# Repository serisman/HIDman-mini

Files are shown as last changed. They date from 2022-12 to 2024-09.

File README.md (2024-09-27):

# HIDman-mini
A USB keyboard/mouse to PS/2 (or AT, Serial) computer adapter.

Based on and compatible with: [HIDman](https://github.com/rasteri/HIDman) by [rasteri](https://github.com/rasteri)
 - In the Makefile, make sure the correct `BOARD_TYPE` is selected and then make sure `OSC_TYPE = OSC_INTERNAL` is enabled and `OSC_TYPE = OSC_EXTERNAL` is disabled.  Re-compile and flash the firmware following the instructions found in the HIDman firmware.
   - For HIDman-mini: Choose `BOARD_TYPE = BOARD_AXP` (for ps/2 and serial support), or `BOARD_TYPE = BOARD_MINI` (for just ps/2 support).
   - For HIDman-micro: Choose `BOARD_TYPE = BOARD_MICRO` (only has ps/2 support).
     - Optionally switch to `BOARD_OPTIONS = OPT_SWAP_KBD_MSC` to make it a bit easier to wire up a combo ps/2 port.

### PCBs
- [HIDman-mini](KiCad%20PCBs/HIDman-mini/)
- [HIDman-micro](KiCad%20PCBs/HIDman-micro/)
- [DB9-to-TTL](KiCad%20PCBs/DB9-to-TTL/)

### 3D Printer Models
- [Cover for HIDman-mini](3D%20Printer%20Models/HIDman-mini/)
- [Shell for DB9-to-TTL](3D%20Printer%20Models/DB9-Shell/)

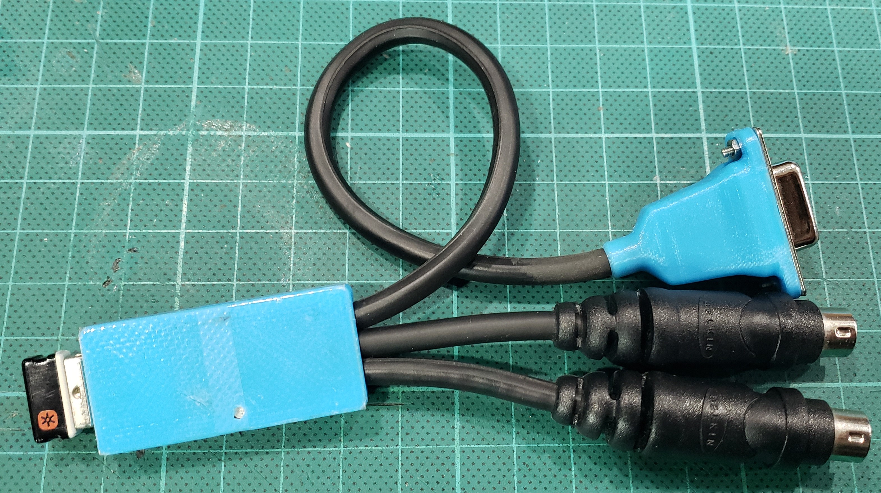
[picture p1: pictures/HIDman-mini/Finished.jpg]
Finished


### Schematics
(for HIDman-mini)
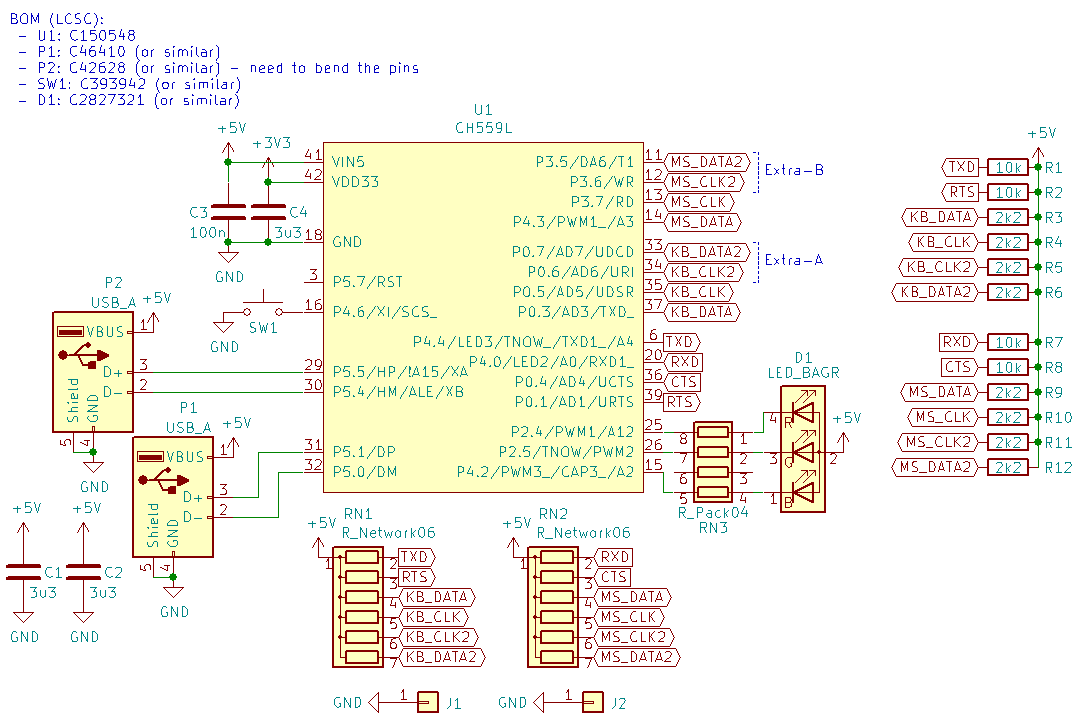
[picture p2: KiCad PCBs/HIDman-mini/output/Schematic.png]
Schematic


(for DB9-to-TTL)
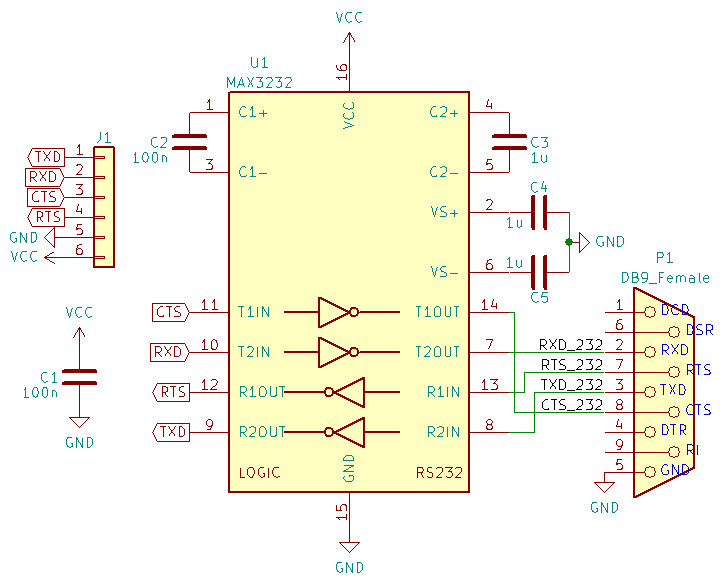
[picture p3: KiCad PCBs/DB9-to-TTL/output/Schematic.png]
Schematic


NOTE: Remember to cross-over TxD <--> RxD, and RTS <--> CTS when connecting the two PCBs!

### Optional Configuration: Combo PS/2 Keyboard/Mouse Connector
(for computers that support it)
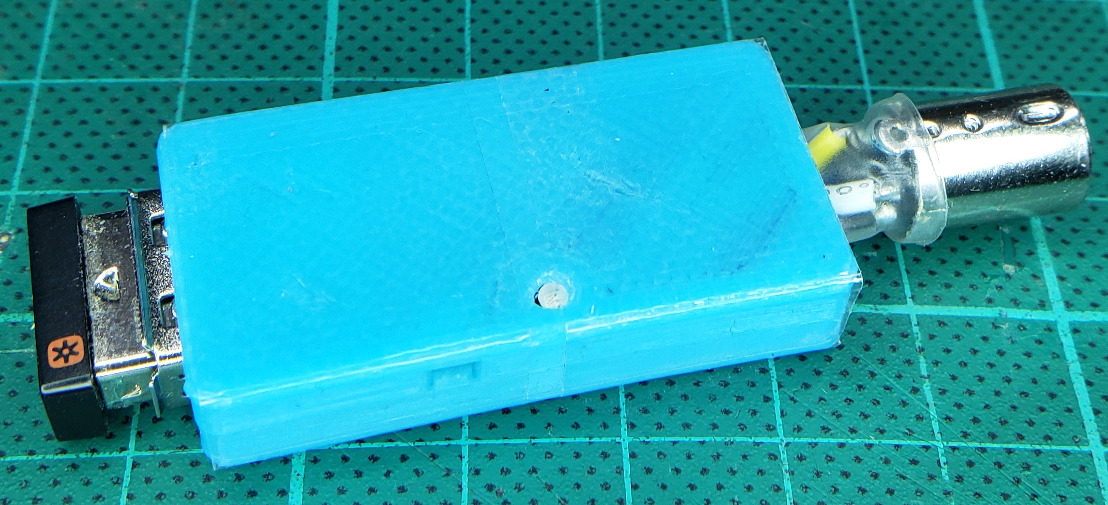
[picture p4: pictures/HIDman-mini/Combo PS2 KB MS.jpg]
Combo PS/2 Keyboard/Mouse

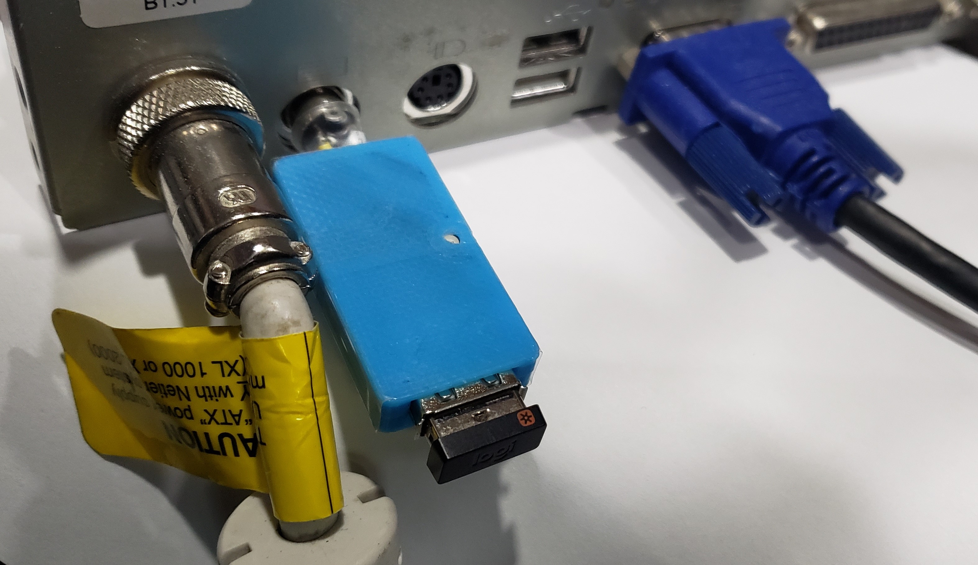
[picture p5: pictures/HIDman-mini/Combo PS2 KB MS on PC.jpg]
Combo PS/2 Keyboard/Mouse on PC


### Copyright and License:
- Copyright (C) 2022 - serisman (github@serisman.com)
- License: [GPL v3 (or later)](LICENSE)

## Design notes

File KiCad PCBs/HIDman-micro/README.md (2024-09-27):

[Home](/README.md)
# PCB: HIDman-micro

Order from [OSHPARK](https://oshpark.com/shared_projects/RKMXx0oz) or upload [gerber.zip](output/gerber.zip) to your favorite PCB board fabricator.

### Notes:
- **WARNING!** Make sure you install the USB port in the correct orientation!
- **WARNING!** Double and Triple check your PS/2 cable pinout to make sure you don't feed 5V where it shouldn't go!

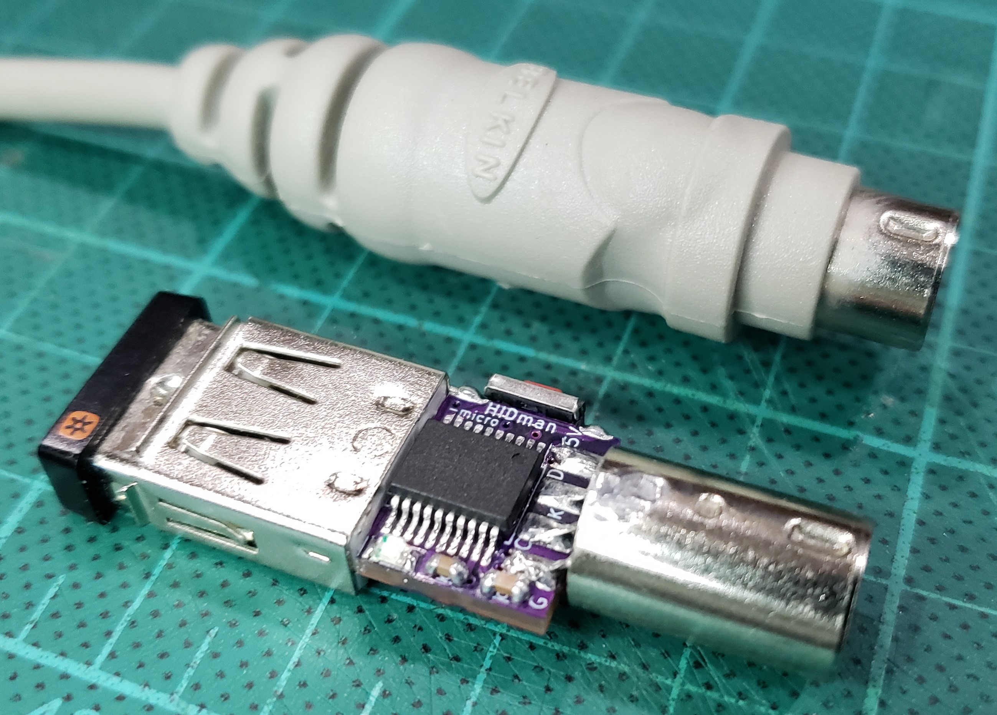
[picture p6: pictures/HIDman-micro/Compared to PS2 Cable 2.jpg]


### Firmware

Compatible with HIDman firmware: https://github.com/rasteri/HIDman

```
make clean
make BOARD_TYPE=HIDMAN_MICRO OSC_TYPE=OSC_INTERNAL flash
... or (if you want to swap Keyboard-Data with Mouse-Clock for easier soldering of combo PS/2 port) ...
make clean
make BOARD_TYPE=HIDMAN_MICRO BOARD_OPTIONS=OPT_SWAP_KBD_MSC OSC_TYPE=OSC_INTERNAL flash
```

### Schematic
- USB port P1 (on bottom side) is required for loading code, and can be used for USB keyboard/mouse (including keyboard/mouse combo wireless adapters).
- Hold down SW1 while plugging USB port into computer to force bootloader.
- Resistors are 0603
- Capacitors are 0603 (100n and 3u3) and 0805 (10u)

**WARNING!** This uses a different pinout than HIDman-mini.  Runtime detection can read P4.7, check if it is LOW or floating, and adjust the PS/2 pins accordingly.

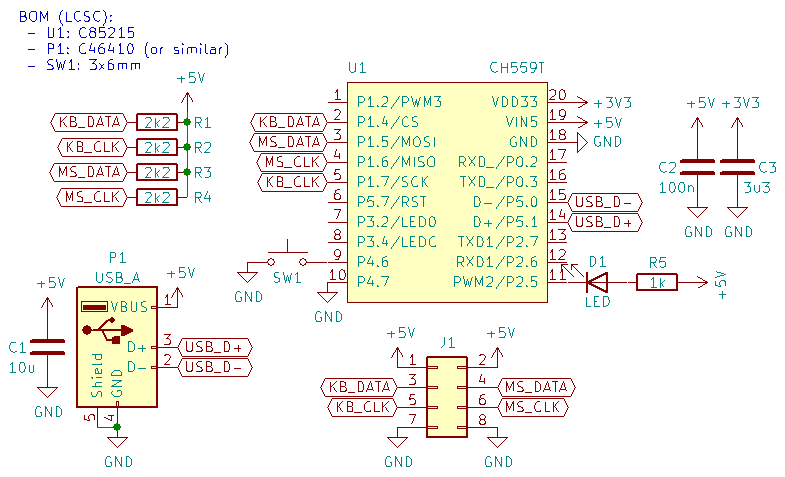
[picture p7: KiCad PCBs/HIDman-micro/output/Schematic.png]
Schematic


### Soldered PCB
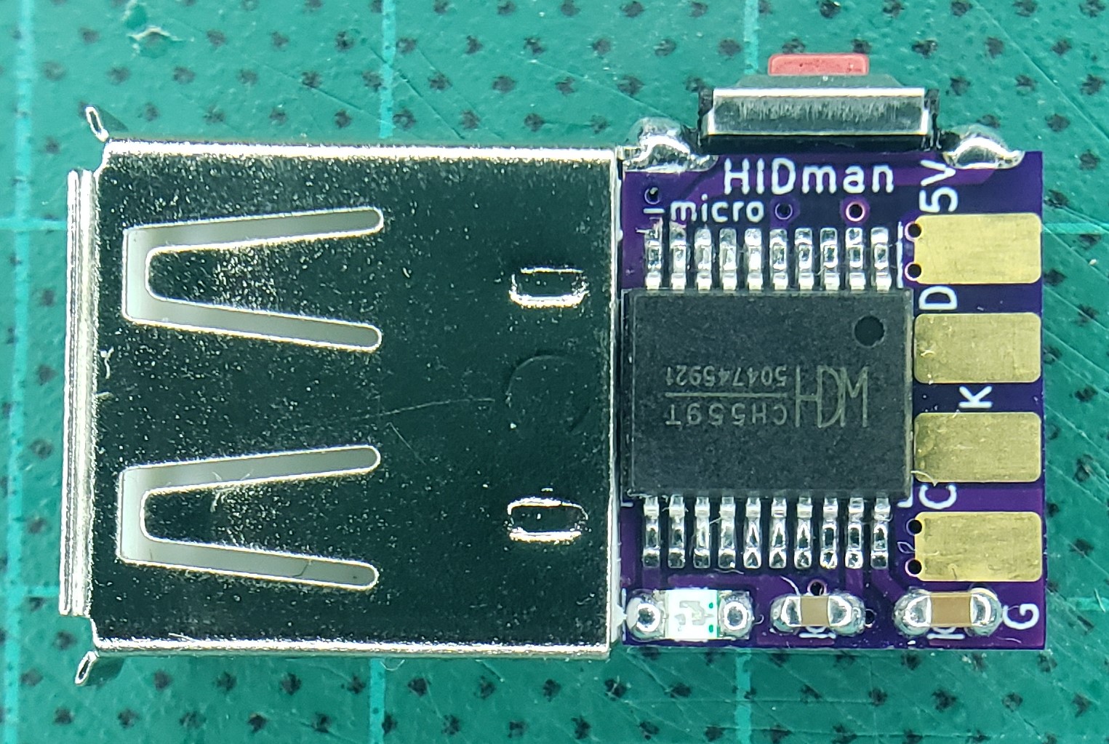
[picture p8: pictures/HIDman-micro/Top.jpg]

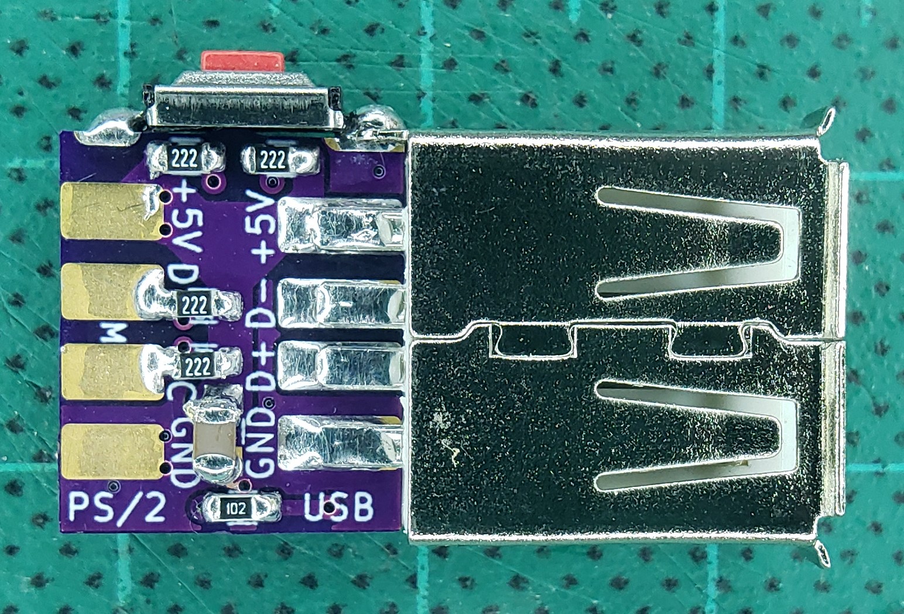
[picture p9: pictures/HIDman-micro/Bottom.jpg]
Bottom


### 3D Render
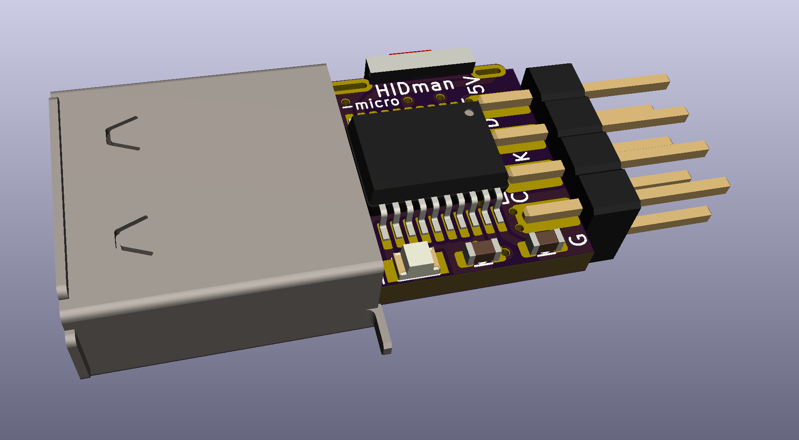
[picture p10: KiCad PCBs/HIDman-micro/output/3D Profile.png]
Profile

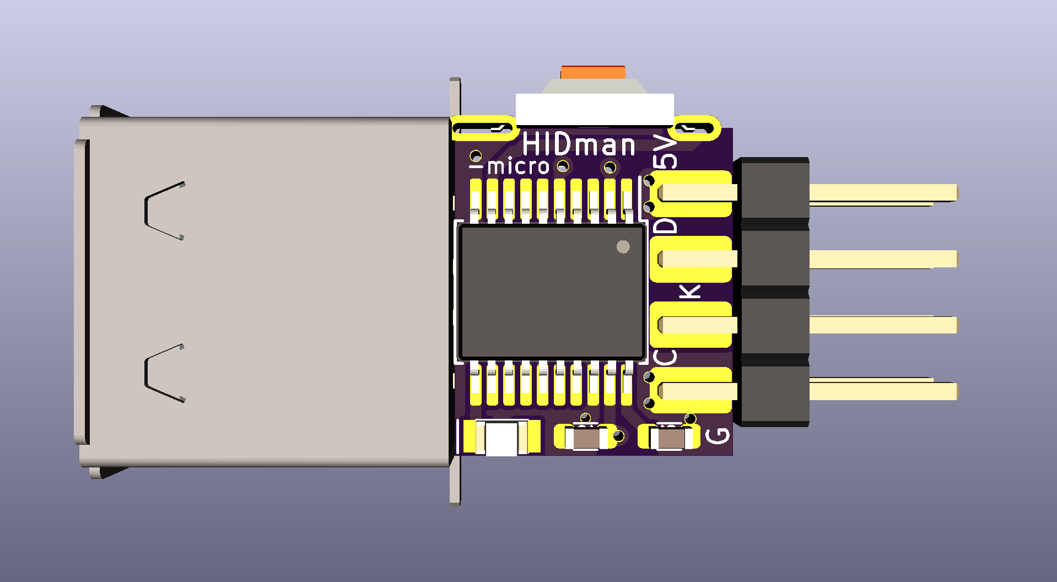
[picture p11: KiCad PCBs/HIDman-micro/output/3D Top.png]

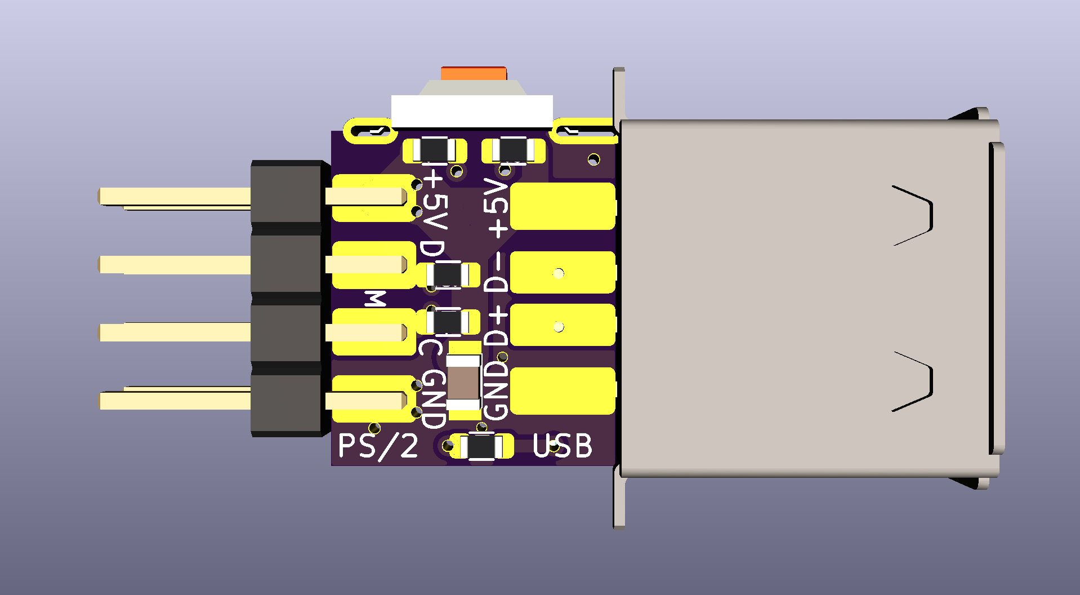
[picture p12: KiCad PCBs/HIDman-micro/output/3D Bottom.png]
Bottom


### Raw PCB
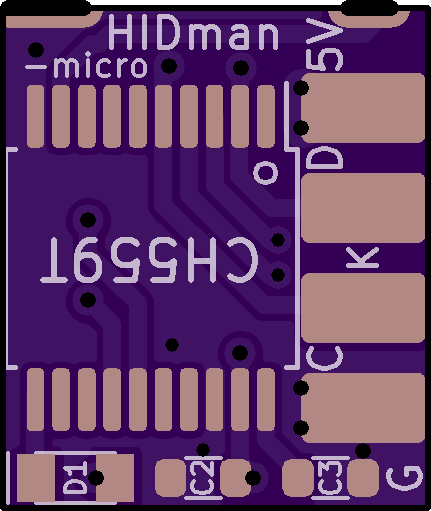
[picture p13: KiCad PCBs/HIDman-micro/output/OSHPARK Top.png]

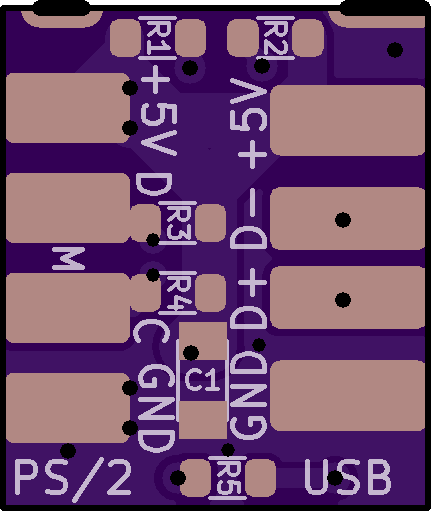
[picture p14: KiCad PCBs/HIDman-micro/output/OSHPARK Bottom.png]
Bottom


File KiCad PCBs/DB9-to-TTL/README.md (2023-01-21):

[Home](/README.md)
# PCB: DB9-to-TTL

Order from [OSHPARK](https://oshpark.com/shared_projects/djSCnWyn) or upload [gerber.zip](output/gerber.zip) to your favorite PCB board fabricator.

### Notes:
- Remember to cross-over TxD <--> RxD, and RTS <--> CTS when connecting to the main PCB!
- The older MAX232 can be used in place of the MAX3232.  Might need to change the capacitor values.

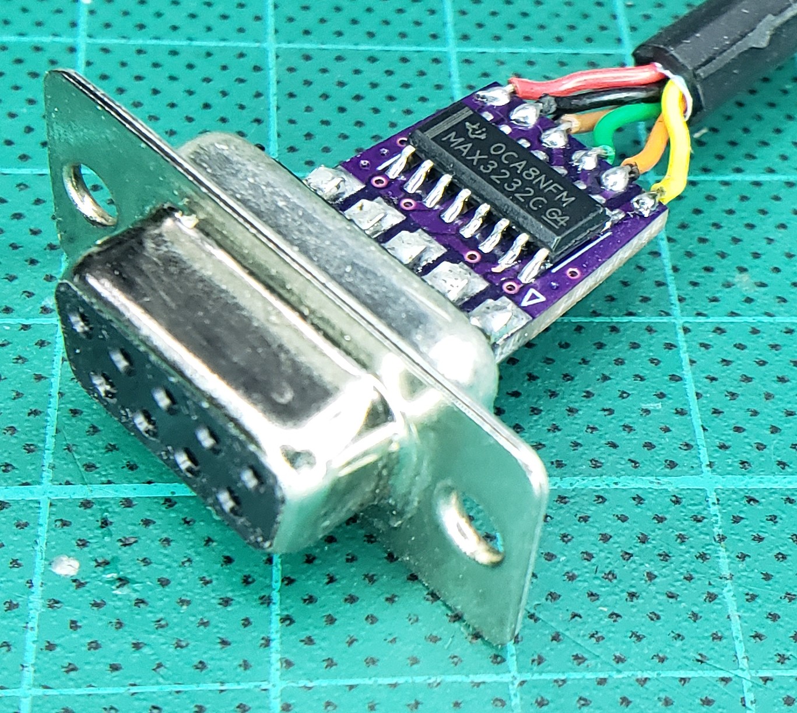
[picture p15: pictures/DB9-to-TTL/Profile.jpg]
Profile


### Schematic
- Capacitors are 0603

Schematic

### Soldered PCB
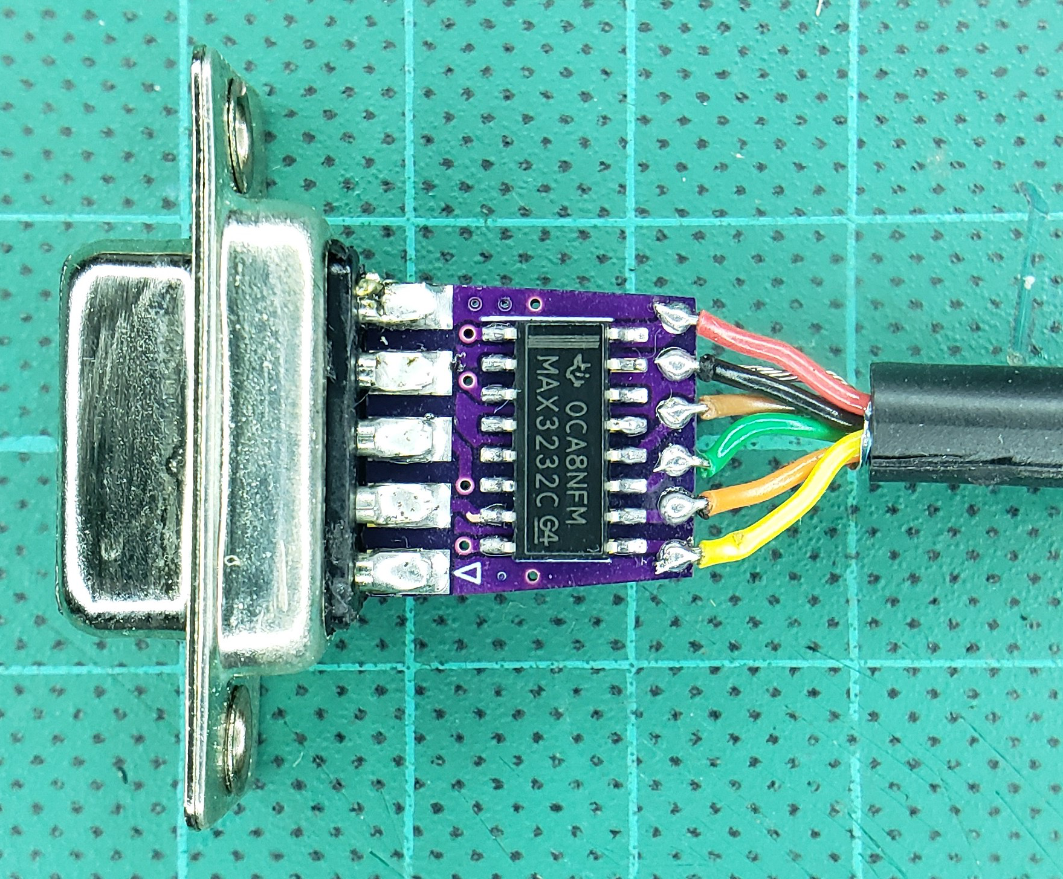
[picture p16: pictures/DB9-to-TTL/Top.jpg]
Top

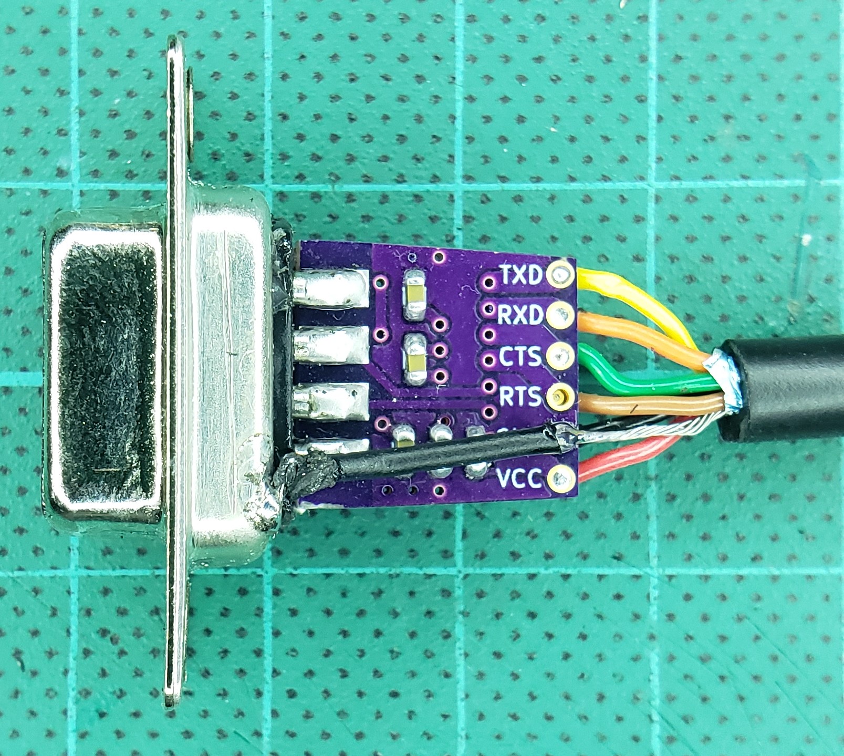
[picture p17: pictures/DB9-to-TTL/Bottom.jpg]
Bottom


### Raw PCB
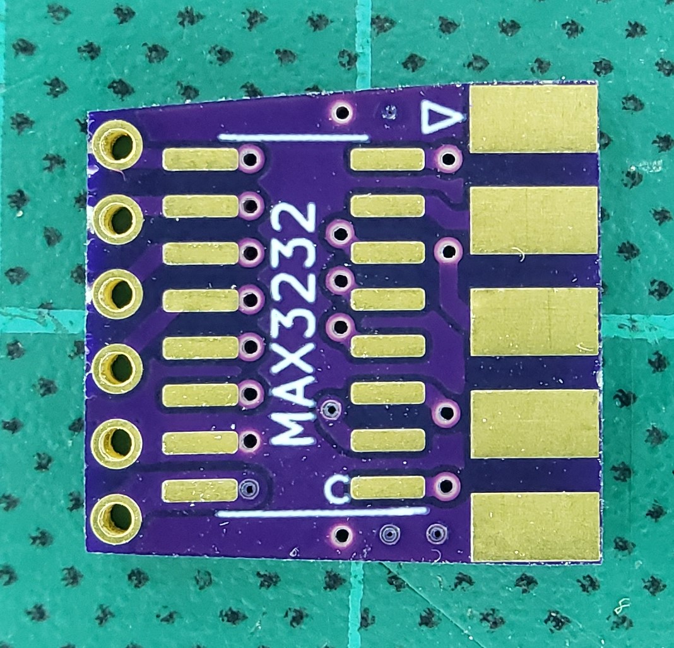
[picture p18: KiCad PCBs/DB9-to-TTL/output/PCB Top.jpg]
PCB Top

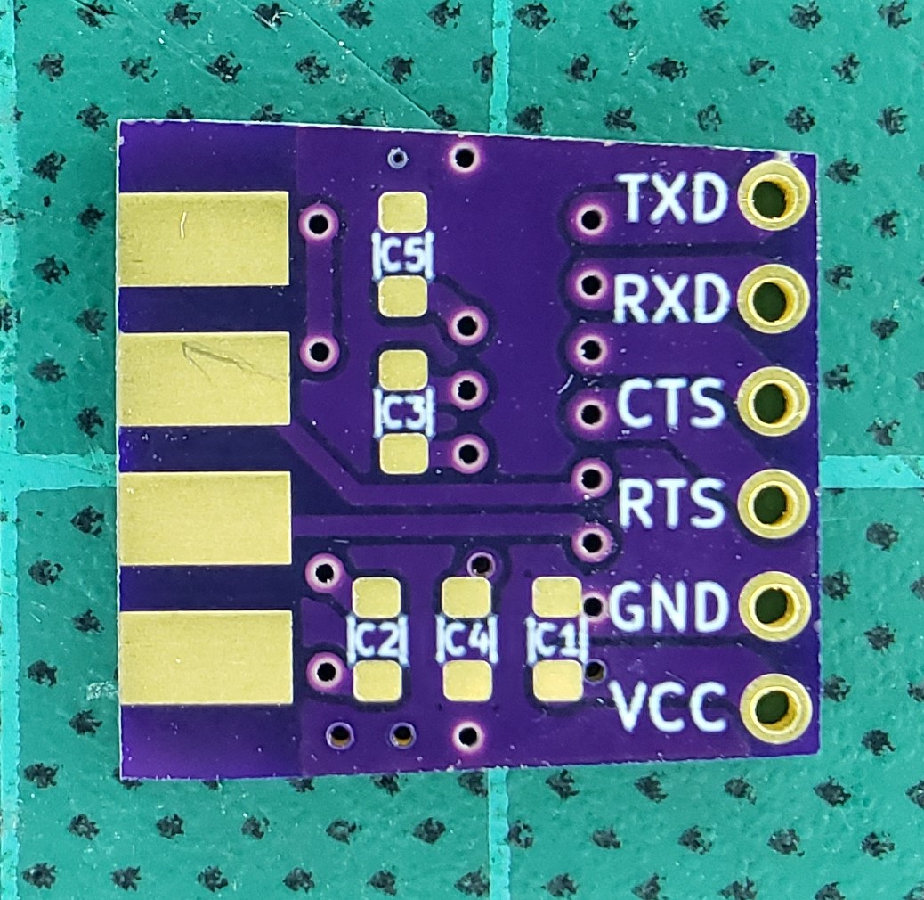
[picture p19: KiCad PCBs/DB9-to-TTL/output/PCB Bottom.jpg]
PCB Bottom


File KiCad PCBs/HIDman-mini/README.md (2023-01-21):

[Home](/README.md)
# PCB: HIDman-mini

Order from [OSHPARK](https://oshpark.com/shared_projects/GPxhWAbz) or upload [gerber.zip](output/gerber.zip) to your favorite PCB board fabricator.

### Notes:
- **WARNING!** Make sure you install the CH559 IC in the correct orientation!  There are three dots, making it confusing at a glance (as me how I know!)
- **WARNING!** Make sure you install the USB port(s) in the correct orientation!
- **WARNING!** Double and Triple check your PS/2 cable pinout to make sure you don't feed 5V where it shouldn't go!

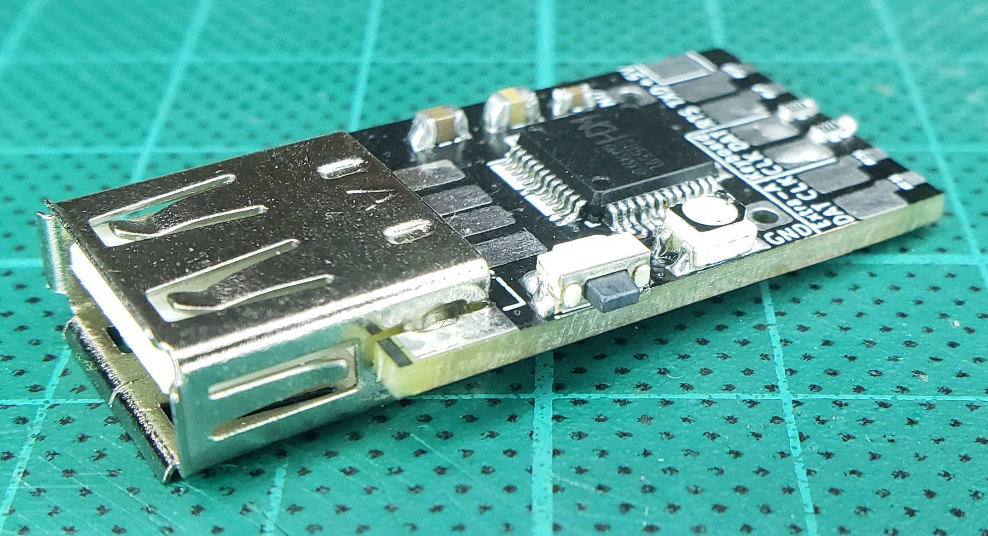
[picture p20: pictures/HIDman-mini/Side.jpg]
Profile


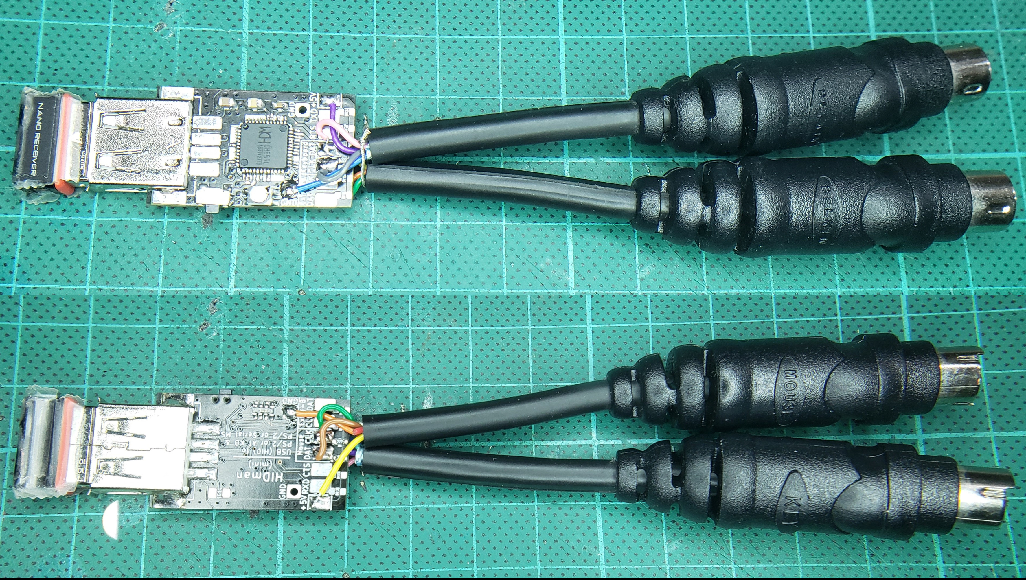
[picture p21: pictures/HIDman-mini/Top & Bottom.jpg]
Soldered


### Schematic
- USB port P1 (on bottom side) is required for loading code, and can be used for USB keyboard/mouse (including keyboard/mouse combo wireless adapters).  It can be installed in the middle of the PCB if USB port P2 is not installed.
- USB port P2 (on top side) is optional, but can be installed if a 2nd USB port is needed.  If installed, USB port P1 will have to be lowered a bit.
- Hold down SW1 while plugging USB port P1 into computer to force bootloader.
- Extra-A and Extra-B are not used for anything (yet).  Therefore R5,R6,R11,R12 are not needed.
- R1,R2,R7,R8 are probably not needed.
- Resistors are 0603
- Capacitors are 0603 (100n) and 0805 (3u3+)
- RN1/RN2 are not actually resistor networks.  They are providing the top/bottom solder pads.
- RN3 is 1k (or whatever works with choosen RGB LED)

Schematic

### Soldered PCB
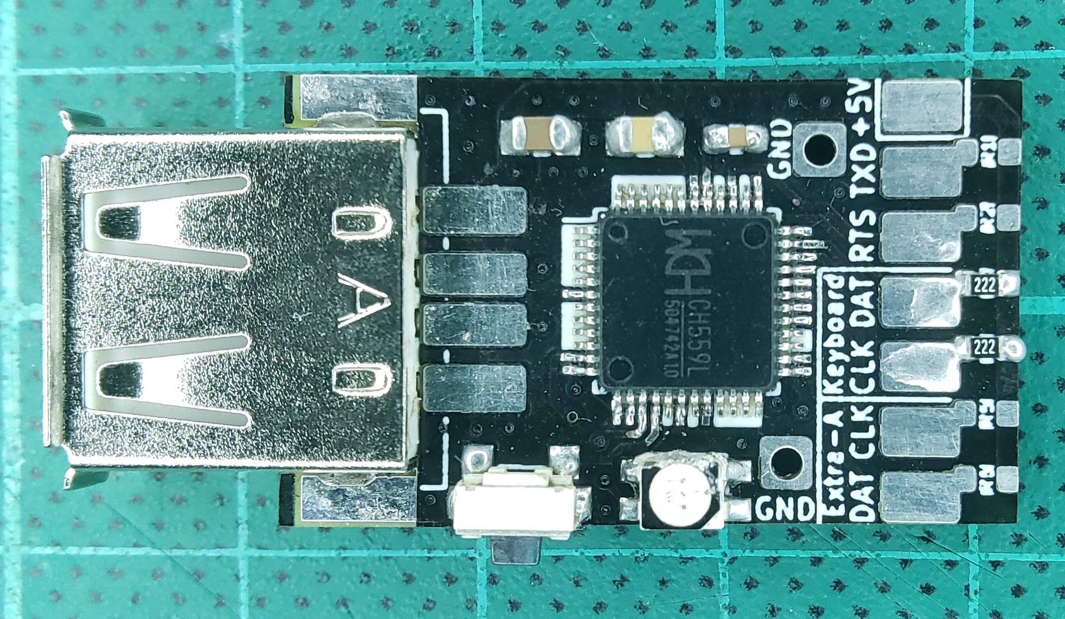
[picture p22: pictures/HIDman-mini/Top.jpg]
Top

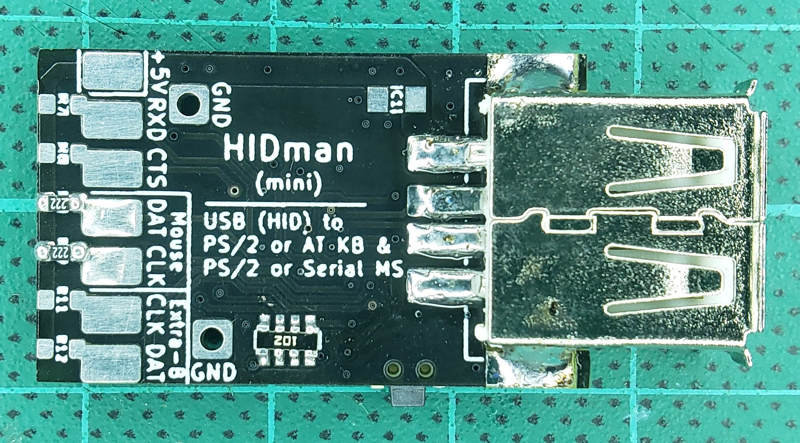
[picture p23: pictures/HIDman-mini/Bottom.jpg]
Bottom


### Raw PCB
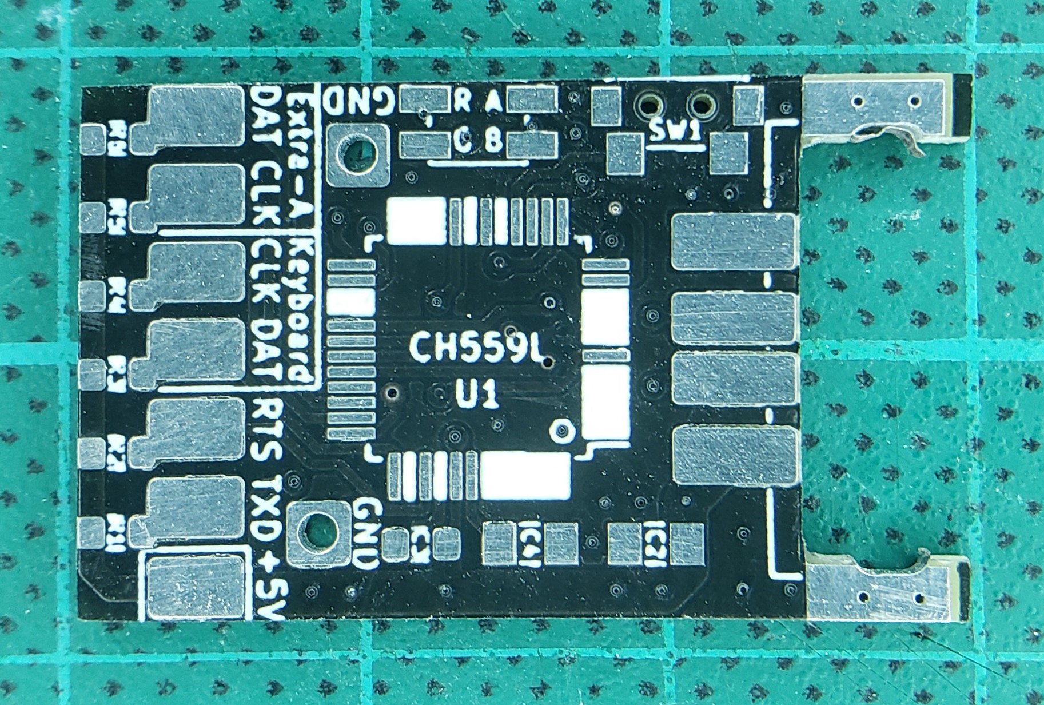
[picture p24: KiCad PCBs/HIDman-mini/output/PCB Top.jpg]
PCB Top

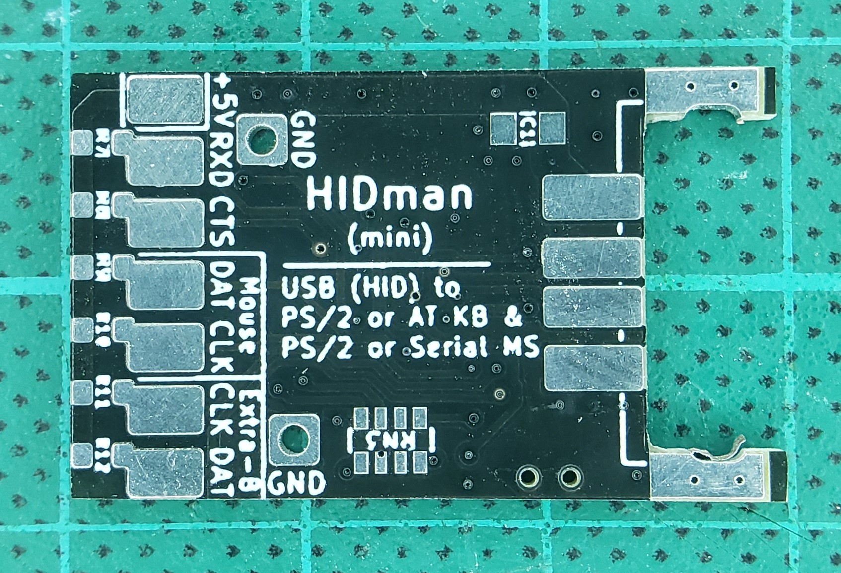
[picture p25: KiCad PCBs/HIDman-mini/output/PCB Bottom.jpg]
PCB Bottom


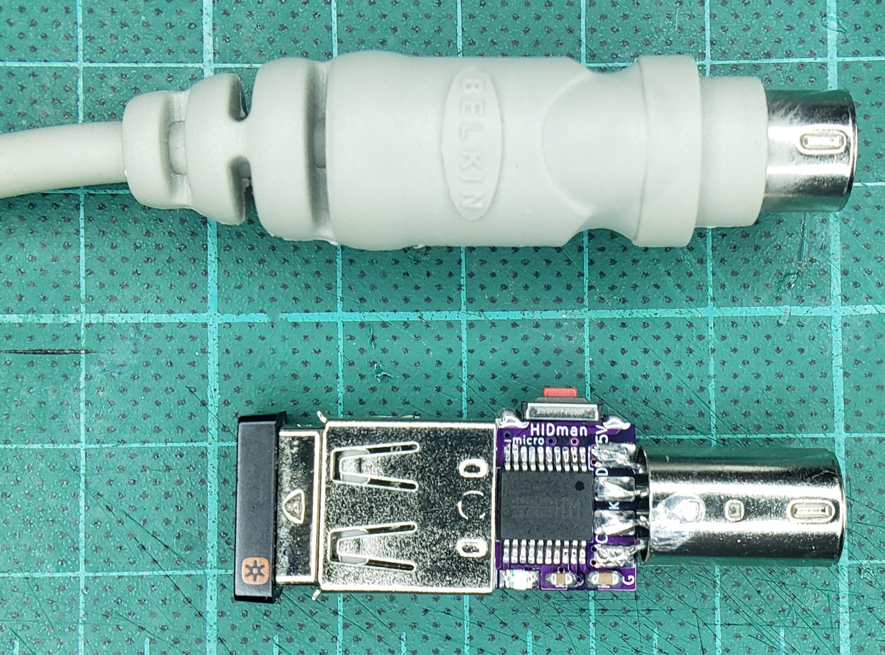
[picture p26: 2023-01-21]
pictures/HIDman-micro/Compared to PS2 Cable.jpg

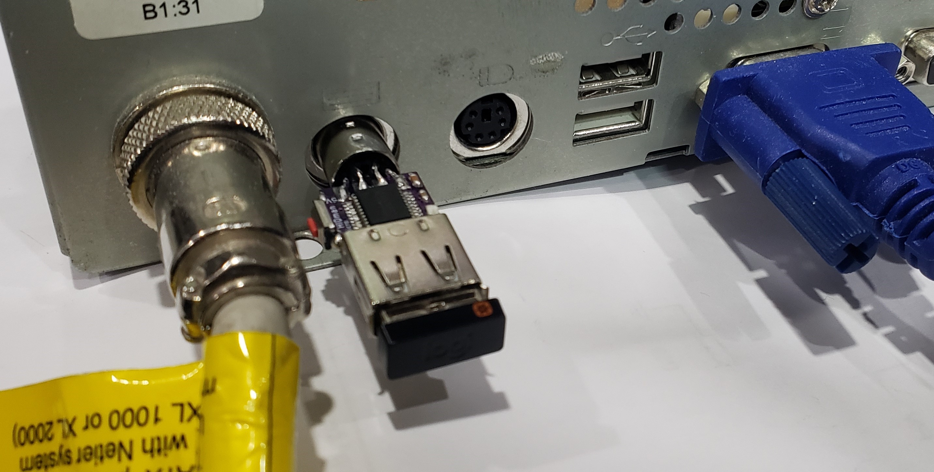
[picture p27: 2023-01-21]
pictures/HIDman-micro/Combo PS2 KB MS on PC.jpg

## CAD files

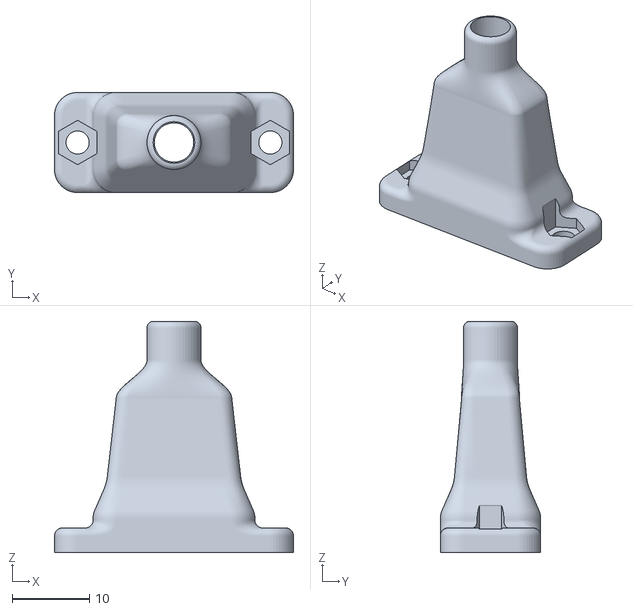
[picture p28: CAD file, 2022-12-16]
3D Printer Models/DB9-Shell/DB9-Shell.stl
31.0 x 13.0 x 30.0

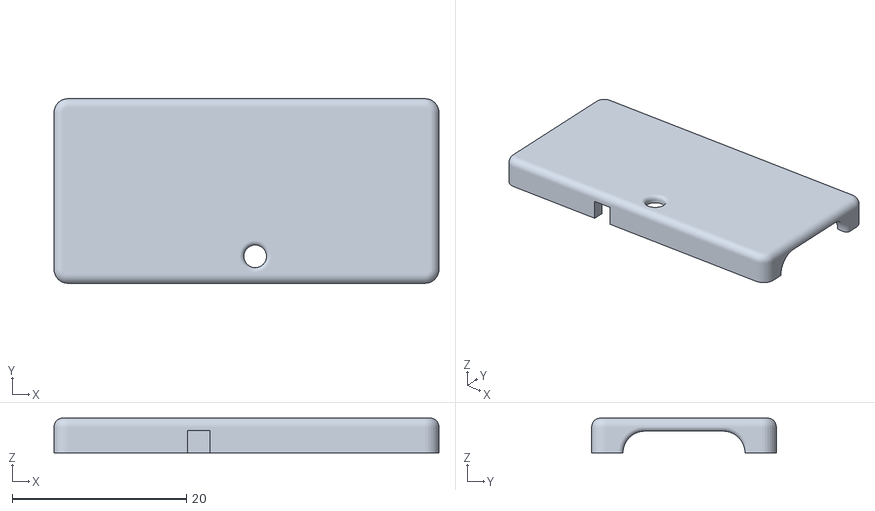
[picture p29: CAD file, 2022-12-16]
3D Printer Models/HIDman-mini/HIDman-mini_Top.stl
44.2 x 21.2 x 4.00

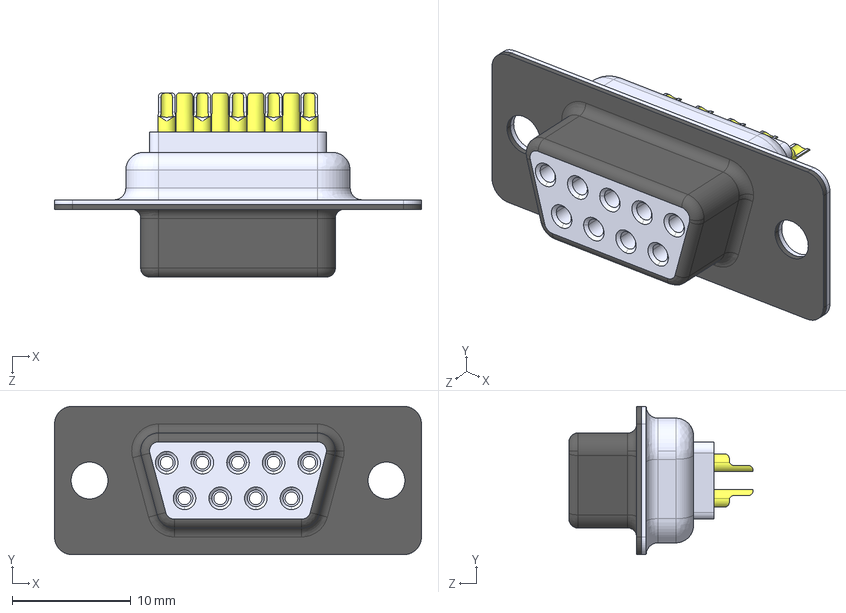
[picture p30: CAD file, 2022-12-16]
KiCad PCBs/DB9-to-TTL/_3dshapes/DB9_Female.step
30.9 x 12.5 x 15.5 mm
H_F_Fr_1
I_F_Fr_1 x 2
H_F_Ba_1
Connector_1 x 9

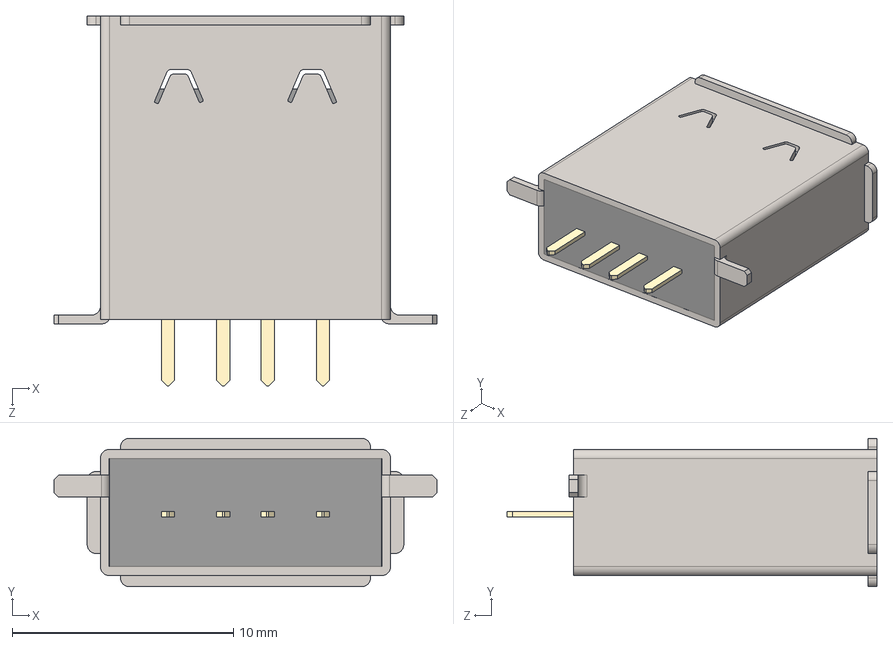
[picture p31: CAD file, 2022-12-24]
KiCad PCBs/HIDman-micro/_3dshapes/USB-A-Edge.step
17.3 x 6.70 x 16.7 mm

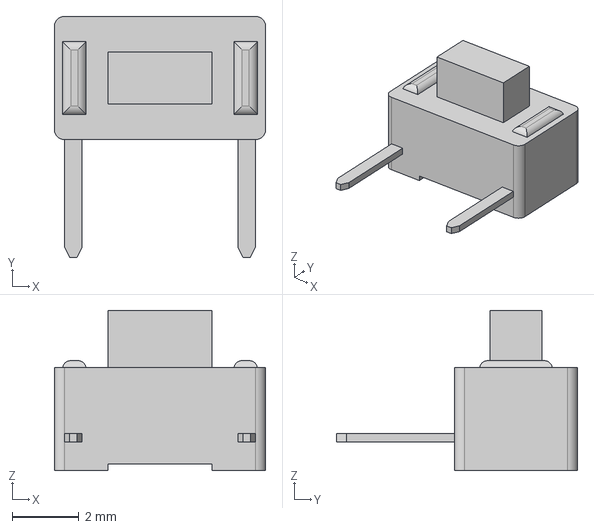
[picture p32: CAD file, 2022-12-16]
KiCad PCBs/HIDman-mini/_3dshapes/Pushbutton_Side.step
6.34 x 7.23 x 4.80 mm

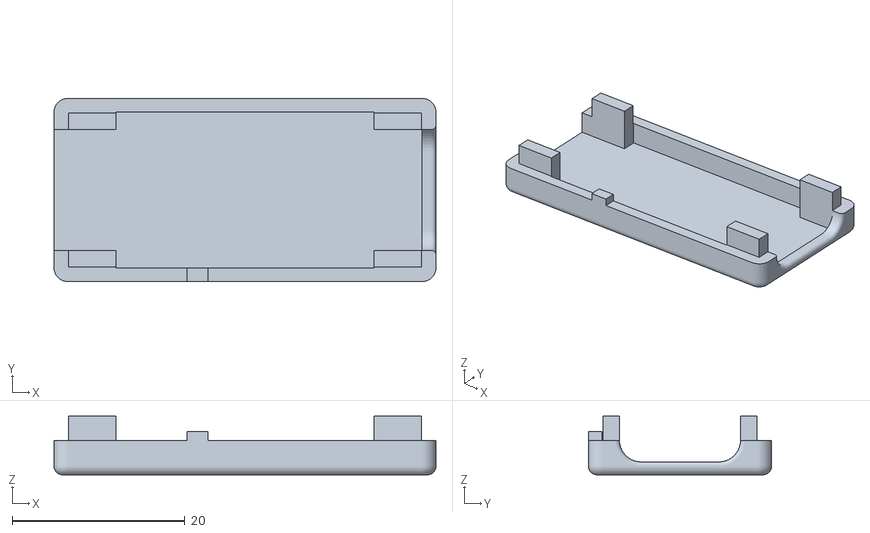
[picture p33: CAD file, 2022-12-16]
3D Printer Models/HIDman-mini/HIDman-mini_Base.stl
44.2 x 21.2 x 6.80

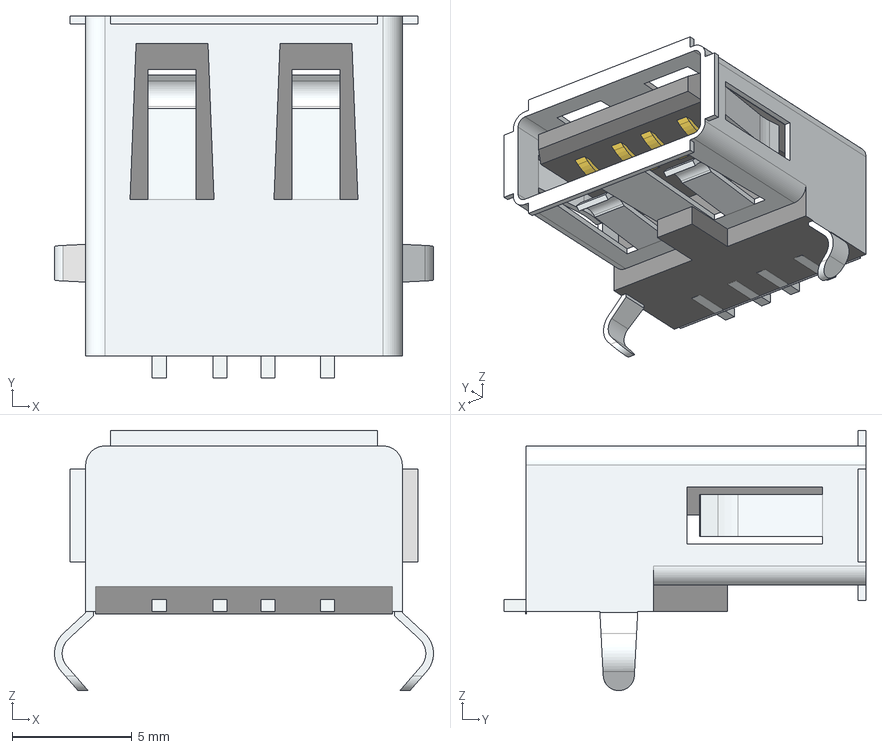
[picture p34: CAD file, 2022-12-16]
KiCad PCBs/HIDman-mini/_3dshapes/A-USB-A-SMT.step
15.8 x 15.1 x 10.8 mm

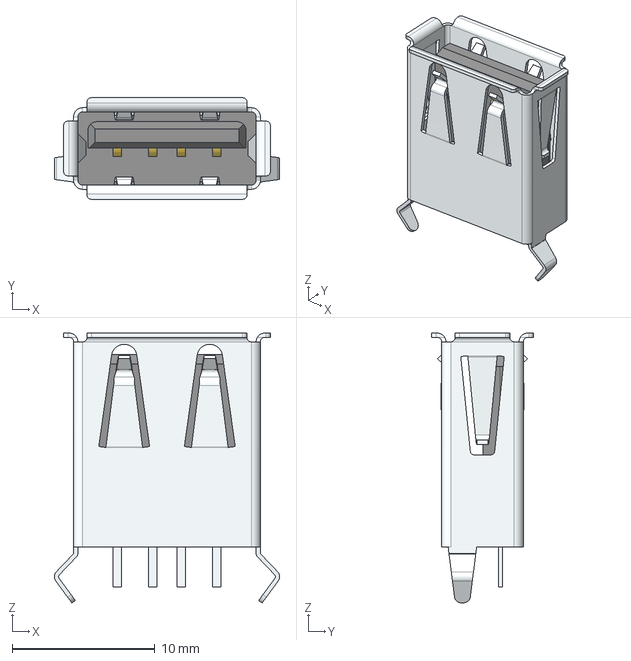
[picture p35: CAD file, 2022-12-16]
KiCad PCBs/HIDman-mini/_3dshapes/A-USB-A-TOP-C.step
15.8 x 7.12 x 18.9 mm

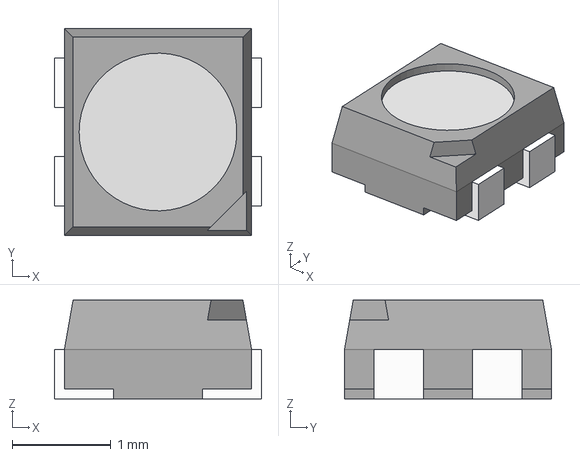
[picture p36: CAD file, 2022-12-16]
KiCad PCBs/HIDman-mini/_3dshapes/RGB_LED_2121.step
2.10 x 2.10 x 1.00 mm

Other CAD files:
3D Printer Models/DB9-Shell/DB9-Shell.f3d
3D Printer Models/HIDman-mini/HIDman-mini.f3d

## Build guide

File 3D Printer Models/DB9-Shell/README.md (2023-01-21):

[Home](/README.md)
# 3D Printer Model: DB9-Shell

- Designed for ~5mm cable.
- Designed for M2.5 (countersunk) screw and nut.  Might work with the DB standard #4-40 screw/nut as well.
- Might need to grind around the holes on the back of the DB9 shell for a better fit (see below).
- Might need to countersink the holes on the front of the DB9 shell for a better fit (see below).

### Files:
- [.STL](DB9-Shell.stl)
- [Fusion 360 Design](DB9-Shell.f3d)

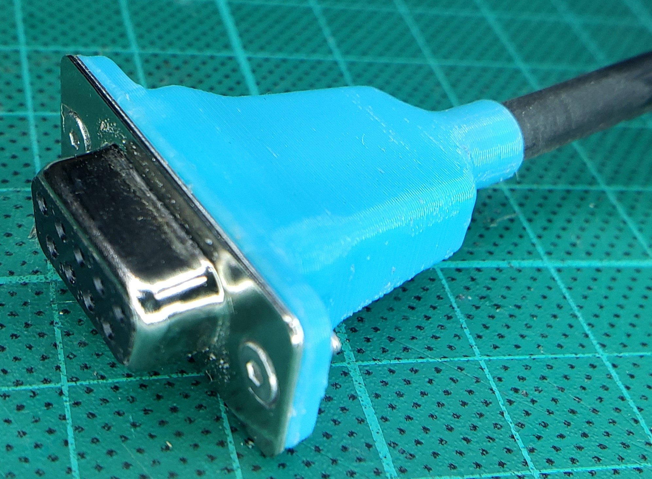
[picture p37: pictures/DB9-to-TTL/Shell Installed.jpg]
Installed


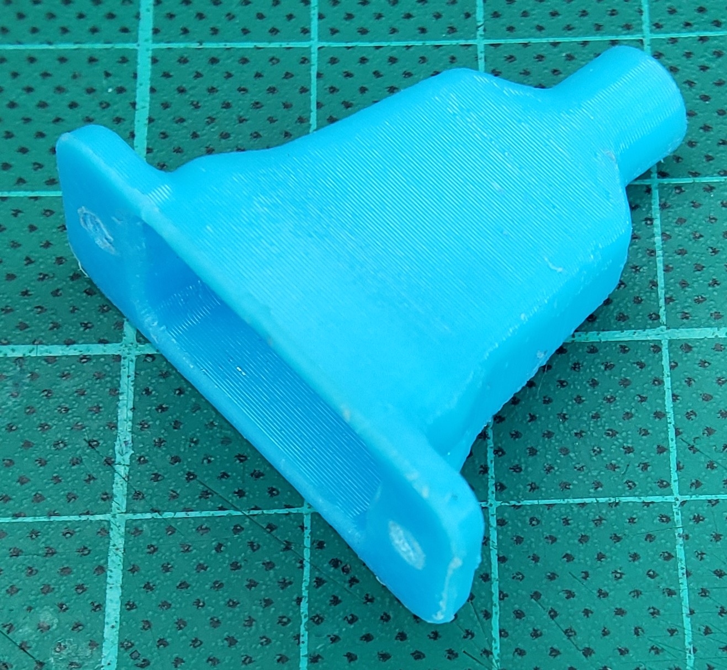
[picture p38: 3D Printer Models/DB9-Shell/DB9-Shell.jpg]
3D Printed


### Grind back of holes
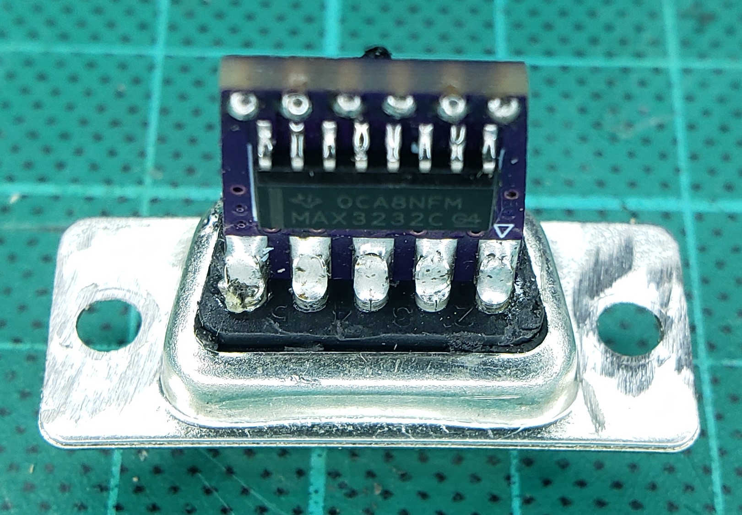
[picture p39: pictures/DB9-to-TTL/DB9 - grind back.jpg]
Grind back


### Countersink front of holes
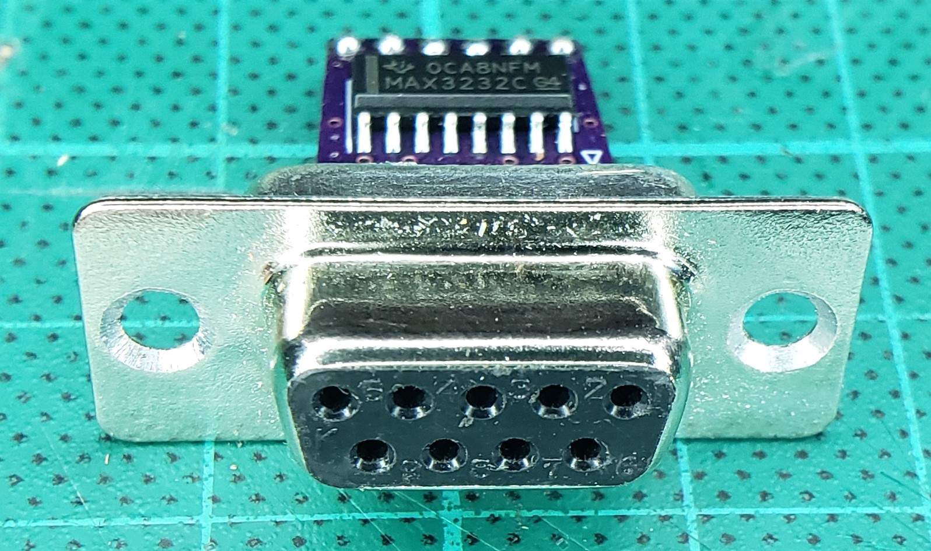
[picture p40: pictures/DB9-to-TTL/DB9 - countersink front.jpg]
Countersink front


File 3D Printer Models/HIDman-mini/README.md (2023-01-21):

[Home](/README.md)
# 3D Printer Model: HIDman-mini

To keep things together, use some superglue between the top and bottom halves, or just wrap in some tape.

### Files:
- [.STL - Top](HIDman-mini_Top.stl)
- [.STL - Base](HIDman-mini_Base.stl)
- [Fusion 360 Design](HIDman-mini.f3d)

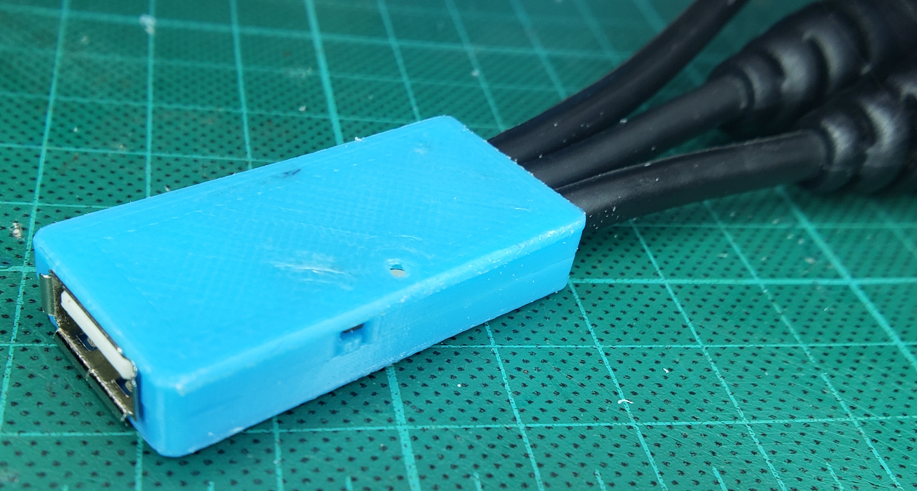
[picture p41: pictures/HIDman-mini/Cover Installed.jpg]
Installed


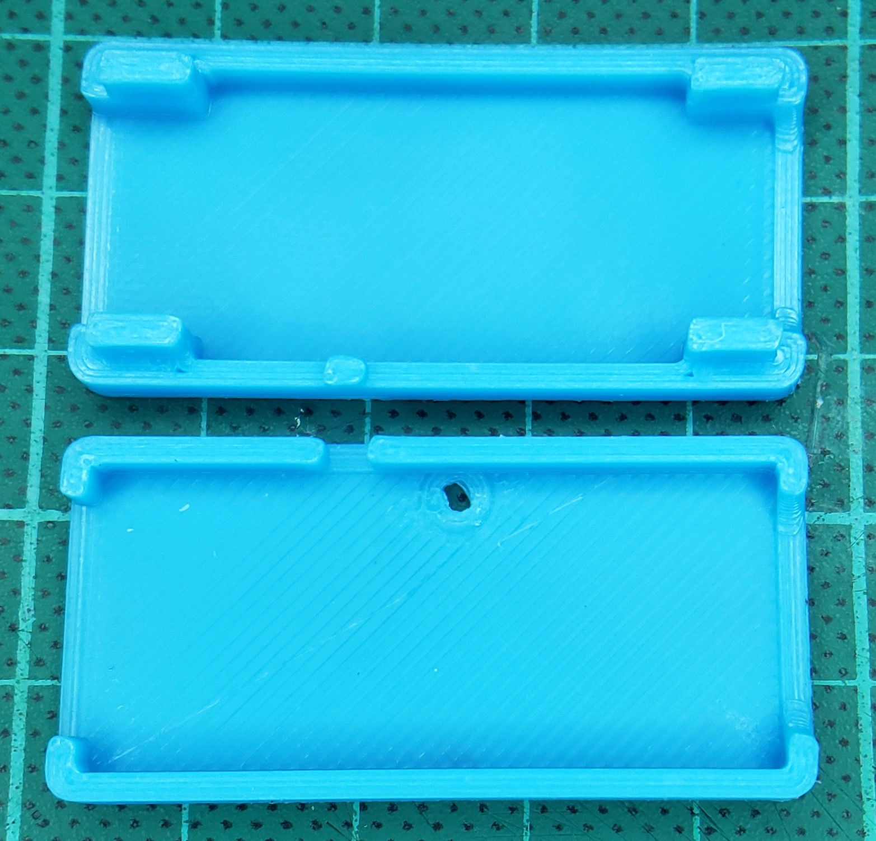
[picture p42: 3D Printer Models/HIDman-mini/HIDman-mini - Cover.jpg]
3D Printed


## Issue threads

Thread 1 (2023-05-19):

PCD Assembly service files?

Tsaukpaetra, 2023-05-19:
I'm a bit inexperienced with ordering PCBs and I see that you have the gerber file for the PCB itself, but I was wondering if you had the other files for ordering assembly from the likes of PCBWay or JLPCB? Their options are a bit daunting.

Ideally if there was a way to one-click configure the project that would be cool, but if I could otherwise get their required files I could possibly bumble about and get it done. I can solder but surface-mount is a bit beyond my abilities. 😇

serisman, 2023-08-30:
Sorry, I have no experience with ordering assembled PCBs.  These PCBs weren't designed with automated assembly in mind.  They have components on both sides of the board, which doesn't work well with typical cheap assembly services like JLCPCB and PCBWay offer.  I designed these for my own limited use, and hand soldered them.  Not too bad with some SMD experience, but probably not what you want to learn on.

GrantMTG, 2023-08-30:
There's a guy on Tindie that sells CH559 breakout boards with the USB jacks and a few other parts mounted. You could cut some cables and solder them to those boards probably.

Closed 2023-08-30.

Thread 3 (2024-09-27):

Firmware?

dukeyusupov, 2024-09-27:
Is the firmware from HIDman suitable? Nothing works for me with it...
Rasteri write:
"I didn't really have anything to do with the mini board, but the firmware in the github definitely won't work.
I've tried to compile the latest firmware for mini boards but it may or may not work"

serisman, 2024-09-27:
It certainly worked with the HIDman firmware a while ago, but that firmware has seen a lot of changes recently and I haven't checked in a year or so.

You might need to use an older version of the firmware or wait until compatibility can be re-checked/fixed.

My fork of the HIDman repo (https://github.com/serisman/HIDman) hasn't been updated in a while, and should still work.

serisman, 2024-09-27:
I just tested with the following version of the HIDman firmware that rasteri custom compiled and it seems to be working fine on one of my HIDman-mini boards:
[hidmanmini.zip](https://github.com/user-attachments/files/17166206/hidmanmini.zip)

Apparently rasteri added an external crystal to his AXP board that has to be disabled in order for the mini to operate.  There are options in the Makefile to switch back to the internal oscillator.

serisman, 2024-09-27:
I just added pre-compiled binaries for v1.1.3 for both HIDman-mini and HIDman-micro available here:
https://github.com/serisman/HIDman-mini/releases/tag/v1.1.3

Closed 2024-09-27.

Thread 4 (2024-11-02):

HIDman-mini issues when interfacing with an Atari Eiffel adapter

klyde2278, 2024-11-02:
Hi Serisman,

I am a French retro computer enthusiast, especially when it comes to the 8-bit and 16-bit Atari computers, my favorites.
I have basic skills in electronics, I am just a hobbyist, and a couple of years ago I have developed a PS/2 to Atari Mega ST keyboard and mouse adapter, based on Didier Mequignon’s Eiffel adapter:
[https://storage.atari-source.org/atari/mirrors/didier.mequignon.free.fr/eiffel-e.htm](https://storage.atari-source.org/atari/mirrors/didier.mequignon.free.fr/eiffel-e.htm)

This adapter translates PS/2 keyboard scan codes, and mouse and joystick signals to Atari ST scan codes, using a PIC16F876 micro-controller. It works like a charm.

I recently came across your HIDman-mini project, and my idea was to add a USB support to the Eiffel adapter, doing something like this:

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

So, I managed to draw a schematic (simplified version without the Atari output, PDF file attached) and I had the PCB made at JLCPCB with a mounted CH559:

Simplified schematics with CH559 to PIC16F876 interface. Atari output and joystick support not shown
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

The PIC16F876 needs the following inputs :

|PIC16F876|SIGNAL|
|---|---|
|P21|KEYB DATA|
|P22|KEYB CLK|
|P23|MOUSE DATA|
|P24|MOUSE CLK|

I have downloaded your HIDman-mini_v1.1.3.bin firmware on your GitHub and was able to successfully flash the CH559 but it does seem to work marginally.

I used a Microsoft Comfort Curve Keyboard on USB1 and a Microsoft Wheel Optical Mouse on USB2 for testing.
The keyboard lights (Num Lock, Caps Lock) don’t light up and the mouse doesn’t work at all on the Atari (The optical sensor lights up). I was not able to test the keyboard further on the Atari, since I had no working mouse, so I am not sure the keyboard 100% works.

I checked continuities and power voltage between the CH559 and the PIC16F876, and they are all ok.

Here are the parameters I used for CH559 flashing. Is it ok?
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

I checked with a scope.
Here is what I have on **CH559 P35 – KEYB CLK**:
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

And for **P37 - KEYB DATA**, when I press the “a” key, I get this:
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

I don’t know if it is the correct PS/2 scan code for “a” (1C F0 1C) but I noticed that every key gives a different pattern, and pressing the same key always gives the same pattern.
I also noticed that the signal is HIGH by default but sometimes goes LOW and remains LOW (when I press “z” or “t” I think), until the next keypress.

But this is what I have for **P13 – MS CLK** it is stuck HIGH (or floats) at 2.5V, even when I move the mouse, no change.
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

And this is **P14 – MS DATA**, it looks like a clock signal with a weird shape?
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

Here is a zoomed version, the signal goes down twice very briefly every 5ms.
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

I also have noticed this clock signal on P25 & P26 (LEDs, I don’t use them).
**P25**
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

**P26**
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

What do you think? What did I do wrong? Do I need to build a specific firmware?

I thank you for developing the HIDman-mini / micro projects!

Emmanuel

serisman, 2024-11-02:
Emmanual,

This repository is really just for hosting the alternate hardware versions (HIDman-mini and HIDman-micro) that I came up with.  The original design and the firmware itself are supported by rasteri's upstream HIDman repo: https://github.com/rasteri/HIDman  You'd probably be better supported by asking firmware questions on that repo.  The firmware attached to this repo is really just a pre-compiled version of what is available on rasteri's repo with a few of the required make flags set.

For what it's worth, the HIDman-mini is pretty much fully compatible with the original AXP hardware (and firmware) with the exception of requiring the internal oscillator instead of using an external crystal.  The HIDman-micro is a more slimmed down design and requires more code changes, mostly around some pinout changes and dropping certain features.

I haven't studied your schematic, but I'd start with a comparison to the official AXP schematic to see what might be different.

klyde2278, 2024-11-02:
Hi! Thank you for your answer.

I based my schematics on your HIDman-mini schematics below and wanted to reuse the KEYB CLK, KEYB DATA, MS CLK and MS DATA outputs:
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

Cheers!

serisman, 2024-11-02:
I just took a look at your schematic, and for the most part it looks pretty reasonable.

But, here are a few things I noticed that may or may not need to be addressed:

- Your schematic seems to be missing the bulk capacitors on the +5V rail(s).  You might also want to remove D1 (or change to a schottky diode for less voltage drop)
- Not sure why you added R4/ZD1.  VDD33 is the output of an internal 3.3v regulator that just need a 3u3 bypass cap.  You don't need to supply it with an external 3.3v supply.
- You might need to install pull-up resistors for the un-used keyboard, mouse, and serial pins (P3.5, P3.6, P0.6, P0.7, P4.4, P4.0, P0.4, P0.1).  Alternatively, you may be able to get away with using a custom firmware build that disables serial support (i.e. BOARD_TYPE = BOARD_MINI should do that)
- I believe the pull-up resistors should be 2k2 for mouse and keyboard pins (not 5k6).  Pull-ups on serial pins can be 10k (5k6 is probably fine as well)

serisman, 2024-11-02:
I also am confused by the comments on your scope screenshots.
You mentioned the following:
```
P35 – KEYB CLK
P37 - KEYB DATA
P13 – MS CLK
P14 – MS DATA
```
but, those are not the correct pins, and don't match your schematic, so I'm not really sure what you meant?
The correct pins should be:
```
P0.5 - Keyboard Clock
P0.3 - Keyboard Data
P3.7 - Mouse Clock
P4.3 - Mouse Data
```

```

serisman, 2024-11-02:
One more thought...

I had a look at that Eiffel adapter's schematic and noticed that there are alternate configurations for the mouse pins RB3/RB2.  They can alternately be hooked up to Rx/Tx on the Atari or the PCA82C251 for CAN? support.  The scope pictures for your mouse pins looks like something with the PIC16F876P may be conflicting with the CH559 (i.e. they are both trying to drive the pins at the same time).  So, I'd double check the firmware you loaded on the PIC to confirm it is the correct one, and not one with some alternate functionality that is trying to do something else with those pins.

klyde2278, 2024-11-02:
Thank you so much for reviewing my schematic.

- I used C4 (100nf) decoupling capacitor, but missed C1 and C2, thank you for pointing me out. I'll add one.
- D1 is a reverse current protection diode, and yes, I noticed that it generates a voltage drop. I'll change it for a Schottky.
- ZD1 and R4: I thought a 3.3V **input** was needed for the CH559 to work, I saw there is an internal voltage regulator in the datasheet, but didn't realised it is an **output**... I'll remove ZD1, R4 and C5.
- I'll add 10k pull-ups for unused serial keyboard and mouse pins.
- I'll change the 5.6k pull-ups (used by the PIC with PS/2 ports on my Eiffel board) with 2.2k.
- I'll compile a new firmware with the HIDman mini options (internal xtal, no serial, board type=mini)
- The PIC is socketed, easy to remove and test with the CH559 only

I'll let you know what it gives.

Cheers,
Emmanuel

serisman, 2024-11-02:
> * ZD1 and R4: I thought a 3.3V **input** was needed for the CH559 to work, I saw there is an internal voltage regulator in the datasheet, but didn't realised it is an **output**... I'll remove ZD1, R4 and C5.

You'll need to leave C5.  The internal regulator needs the external bypass capacitor.

You can probably leave the 5.6k pull-ups for now.  You aren't using an actual PS/2 keyboard/mouse.  So, if 5.6k works for the PIC, it will probably work fine with the CH559 as well.  You also probably don't need the pull-ups on the unused keyboard/mouse pins.  I don't believe the current firmware does anything with those.  But, the pull-ups on the serial pins (and/or compile without serial support) would be good to have to make sure the firmware isn't trying to communicate with a serial mouse.

klyde2278, 2024-11-02:
Thank you, I'll check that out tomorrow, and I'll let you know.

Are the parameters I use for flashing the CH559 correct?

Cheers!
Emmanuel

klyde2278, 2024-11-04:
Hi!

I did further testing on 2 diffrents PCBs, with what I consider the bare minimum.

- CH559 powered up with 5V + 100nF decoupling capacitor (no 3.3µF decoupling cap though) + 3.3V output with a 3.3µF bypass cap,
- No PIC16F876 installed,
- 5.6K pull-ups,
- the rest is floating.

Here is the schematic:
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

I built a firmware from Rasteri sources, with the HIDman-mini Makefine options (BOARD_TYPE=MINI, OSC_TYPE=OSC_INTERNAL,), and I tried with your precompiled HIDman-mini 1.1.3 too.

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

KB_CLK and KB_DATA seems ok.
This is what I have when pressing letter "a":
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

But still a no-go for the mouse, I tried with 3 different known working USB mice (HP HSTNN-PM12, Logitech M100, Microsoft Optiocal Wheel). The optical sensor light up each time, but MS_CLK and MS_DATA lines are stuck HIGH whether I move the mouse or press the buttons.

I also noticed that P15, P25 and P26 (RGB LED, not installed on my PCB) reacts when I move the mouse and press the buttons, so there is some "life", but no outputs on P13 and P14.

My next step I think will be to have your HIDman-mini PCB made, in order to connect it to my original PS/2 Eiffel PCB and see what I end up with...

Cheers!
Emmanuel

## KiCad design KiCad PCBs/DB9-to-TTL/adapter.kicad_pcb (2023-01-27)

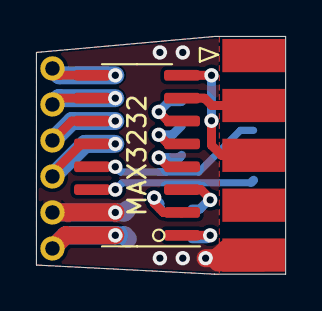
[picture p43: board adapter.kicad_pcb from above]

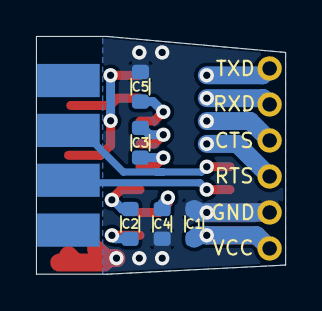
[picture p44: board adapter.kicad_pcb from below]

Board: 2 copper layers, 13.8 x 13.2 mm, 8 parts (6 on the bottom side), 16 nets.

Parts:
C1, C2: 100n; C_0603
C3, C4, C5: 1u; C_0603
J1: Conn_01x06; PinHeader_1x06_P2.00mm_Vertical
P1: DB9_Female; DSUB-9_Female_EdgeMount_P2.77mm
U1: MAX3232; SOP-16_3.9x9.9mm_P1.27mm

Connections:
/CTS_232: P1.8, U1.14
/RTS_232: P1.7, U1.13
/RXD_232: P1.2, U1.7
/TXD_232: P1.3, U1.8
CTS: J1.3, U1.11
GND: C1.2, C4.1, C5.1, J1.5, P1.5, U1.15
unnamed: C2.1, U1.1
unnamed: C2.2, U1.3
unnamed: C3.1, U1.4
unnamed: C3.2, U1.5
unnamed: C4.2, U1.2
unnamed: C5.2, U1.6
RTS: J1.4, U1.12
RXD: J1.2, U1.10
TXD: J1.1, U1.9
VCC: C1.1, J1.6, U1.16

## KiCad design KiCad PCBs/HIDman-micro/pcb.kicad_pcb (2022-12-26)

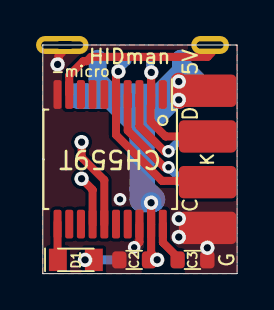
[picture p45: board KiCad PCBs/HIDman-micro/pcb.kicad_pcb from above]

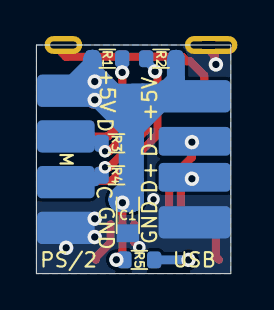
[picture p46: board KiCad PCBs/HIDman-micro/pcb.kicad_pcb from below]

Board: 2 copper layers, 10.8 x 12.7 mm, 13 parts (6 on the bottom side), 12 nets.

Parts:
C1: 10u; C_0805
C2: 100n; C_0603
C3: 3u3; C_0603
D1: LED; LED_0805
J1: Conn_02x04_Odd_Even; PinHeader_2x04_P2.54mm_Edge
P1: USB_A; USB_A_Female_SMD_Edge
R1, R2, R3, R4: 2k2; R_0603
R5: 1k; R_0603
SW1: SW_Push; SW_SPST_Edge
U1: CH559T; SSOP-20_5.3x7.2mm_P0.65mm

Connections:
+3V3: C3.1, U1.20
+5V: C1.1, C2.1, J1.1, J1.2, P1.1, R1.1, R2.1, R3.1, R4.1, R5.1, U1.19
GND: C1.2, C2.2, C3.2, J1.7, J1.8, P1.4, SW1.1, U1.10, U1.18
KB_CLK: J1.5, R2.2, U1.5
KB_DATA: J1.3, R1.2, U1.2
MS_CLK: J1.6, R4.2, U1.4
MS_DATA: J1.4, R3.2, U1.3
unnamed: D1.1, U1.11
unnamed: D1.2, R5.2
unnamed: SW1.2, U1.9
USB_D+: P1.3, U1.14
USB_D-: P1.2, U1.15

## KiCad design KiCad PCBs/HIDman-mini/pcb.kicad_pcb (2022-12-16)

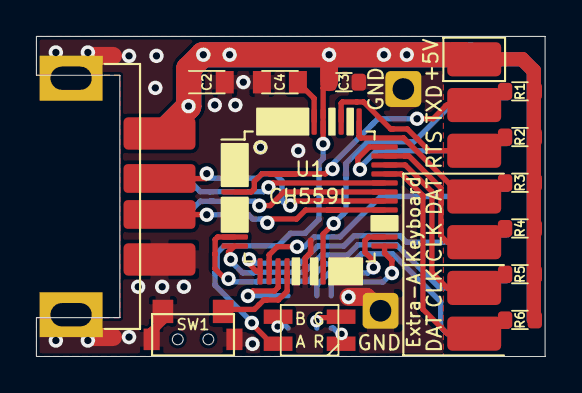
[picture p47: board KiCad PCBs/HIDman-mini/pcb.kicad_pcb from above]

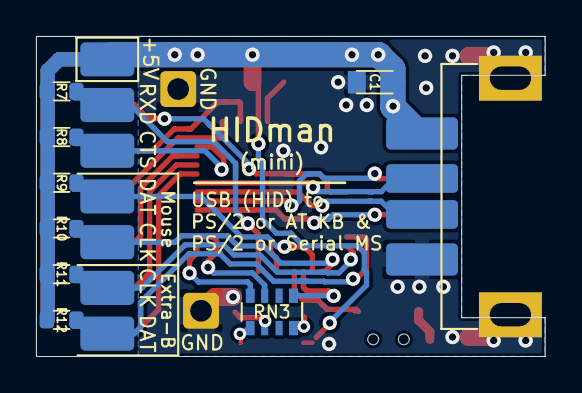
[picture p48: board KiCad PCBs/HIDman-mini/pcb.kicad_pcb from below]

Board: 2 copper layers, 28.3 x 17.8 mm, 26 parts (9 on the bottom side), 26 nets.

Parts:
C1, C2, C4: 3u3; C_0805
C3: 100n; C_0603
D1: LED_BAGR; LED_BAGR_3528
J1, J2: Conn_01x01; PinHeader_1x01_P2.54mm_Vertical
P1: USB_A; USB_A_Female_SMD_Edge
P2: USB_A; USB_A_Female_SMD_Top
R1, R2, R3, R4, R5, R6, R7, R8, R9, R10, R11, R12: 10k; R_0603
RN1, RN2: R_Network06; R_Array_SIP7_Edge
RN3: R_Pack04; R_Array_Convex_4x0603
SW1: SW_Push; SW_Push_3.5x4.55_Side
U1: CH559L; LQFP-48_7x7mm_P0.5mm

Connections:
+3V3: C4.1, U1.42
+5V: C1.1, C2.1, C3.1, D1.2, P1.1, P2.1, R1.1, R2.1, R3.1, R4.1, R5.1, R6.1, R7.1, R8.1, R9.1, R10.1, R11.1, R12.1, RN1.1, RN2.1, U1.41
CTS: R8.2, RN2.3, U1.36
GND: C1.2, C2.2, C3.2, C4.2, J1.1, J2.1, P1.4, P2.4, P2.5, SW1.2, U1.18
KB_CLK: R4.2, RN1.5, U1.35
KB_CLK2: R5.2, RN1.6, U1.34
KB_DATA: R3.2, RN1.4, U1.37
KB_DATA2: R6.2, RN1.7, U1.33
MS_CLK: R10.2, RN2.5, U1.13
MS_CLK2: R11.2, RN2.6, U1.12
MS_DATA: R9.2, RN2.4, U1.14
MS_DATA2: R12.2, RN2.7, U1.11
unnamed: D1.1, RN3.4
unnamed: D1.3, RN3.2
unnamed: D1.4, RN3.1
unnamed: P1.2, U1.32
unnamed: P1.3, U1.31
unnamed: P2.2, U1.30
unnamed: P2.3, U1.29
unnamed: RN3.5, U1.15
unnamed: RN3.7, U1.26
unnamed: RN3.8, U1.25
unnamed: SW1.1, U1.16
RTS: R2.2, RN1.3, U1.39
RXD: R7.2, RN2.2, U1.20
TXD: R1.2, RN1.2, U1.6

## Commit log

2022-12-16 Add KiCad PCBs and 3D Printer Models
    [A-USB-A-SMT.step, A-USB-A-TOP-C.step, DB9-Shell.f3d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]
2022-12-16 add Gerber files
    [adapter-B_Cu.gbr, adapter-B_Mask.gbr, adapter-B_Paste.gbr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]
2022-12-24 Add HIDman-micro. An even smaller version, using CH559T.
    [USB-A-Edge.step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]
2022-12-26 Tweak pad/track size/spacing
    [pcb-B_Cu.gbr, pcb-B_Mask.gbr, pcb-B_Paste.gbr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]
2023-01-27 More verbose DB9-TTL Schematic
    [adapter.kicad_pcb, adapter.sch]
